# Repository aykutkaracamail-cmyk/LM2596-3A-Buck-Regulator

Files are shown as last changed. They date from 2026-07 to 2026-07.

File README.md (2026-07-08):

# KiCAD LM2596 Buck Regulator Project

Bu projede giriş gerilimini düşürerek çıkışa aktarmak amaçlanmıştır. Giriş gerilimini düşüren bu tip devrelere SMPS (Switched-Mode Power Supply) devreleri denilmiş olup, bu proje özelinde LM2596-ADJ entegresi kullanılmıştır. 

Çıkıştaki ani akım ihtiyacını karşılayabilmek ve voltaj çakılmasını engelleyebilmek için giriş kısmında 50V dayanımlı iki tane 470 uF'lık polarize kondansatör kullanılmıştır. Anahtarın açık olduğu esnada yük üzerindeki akımı kaybetmemek amacıyla endüktans 68 uH olarak seçilmiş olup, devreden geçecek olan maksimum akımın 3A düzeyinde olması planlandığından ters yön diyotu Schottky (5A) olarak seçilmiştir. Ayrıca yükün üstündeki gerilimin ripple (dalgalanma) katsayısının düşürülmesi amacıyla çıkışa paralel bağlı olan iki tane 220 uF'lık 35V dayanımlı polarize kondansatör kullanılmıştır. Versiyonlar arası komponentler değişiklik gösterebilir. Güncel stok durumları ve üretim maaliyetleri nedeniyle komponentler değiştirilmiştir.

📊 LTspice Simülasyon Sonucu



📊 PCB İlk Bakış



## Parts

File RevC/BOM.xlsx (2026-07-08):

Category | Quantity | References | Value | Package | Stock Code | Unit Cost | Tedarikçi Firma | Stok Adedi | Unit Cost (100 Adet) | Cost (100 adet kart) | Unit Cost (500 Adet) | Cost (500 adet kart) | Unit Cost (1000 Adet) | Cost (1000 adet kart) | Alternatif | Tedarikçi Firma
Capacitors | 2 | C1,C4 | 470 uF 50 V | Through Hole, D10mm×L20mm (P=5mm) | 01EC4236 (https://www.lcsc.com/product-detail/C2760863.html) | 0.10300 USD (en az 5 tane) | LCSC | 2720 | 0.08310 USD | 0.0831*200=16.62 USD (kondansatörlerden 200 tane alınmıştır) | 0.06050 USD | 0.0605*1000=60.50 USD (kondansatörlerden 1000 tane alınmıştır) | 0.06050 USD | 0.0605*2000=121.00 USD (kondansatörlerden 2000 tane alınmıştır) | RVT1H471M1213 (https://www.lcsc.com/product-detail/Aluminum-Electrolytic-Capacitors-SMD_470uF-50V-20_C90272.html) | LCSC
Capacitors | 2 | C2,C3 | 100 nF 50 V | 0402 | C0402B104K500NT (https://www.lcsc.com/product-detail/C17702730.html) | 0.00530 USD (en az 100 tane) | LCSC | 3100 | 0.00530 USD | 0.0053*200=1.06 USD (kondansatörlerden 200 tane alınmıştır) | 0.00420 USD | 0.0042*1000=4.20 USD (kondansatörlerden 1000 tane alınmıştır) | 0.00420 USD | 0.0042*2000=8.40 USD (kondansatörlerden 2000 tane alınmıştır) | CC0402KRX7R9BB104 (https://www.lcsc.com/product-detail/C131394.html) | LCSC
Inductor | 1 | L1 | 47 uH 3 A ISAT 4.5 A | SMD, 11.5×10.2×4.0mm | SMMS1040-470M (https://www.lcsc.com/product-detail/C149599.html) | 0.19380 USD (en az 5 tane) | LCSC | 64135 | 0.15080 USD | 0.1508*100=15.08 USD | 0.12980 USD | 0.1298*500=64.90 USD | 0.11110 USD | 0.1111*1000=111.10 USD | CYH127-47UH (https://www.lcsc.com/product-detail/Inductors-SMD_SHOU-HAN-CYH127-47UH_C2929503.html) | LCSC
Miscellaneous | 2 | J1,J2 | - | Through Hole, P=3.5mm (2 kutup) | DB301V-3.5-2P-GN-S (https://www.lcsc.com/product-detail/C695629.html) | 0.08420 USD (en az 5 tane) | LCSC | 97295 | 0.06170 USD | 0.0617*200=12.34 USD (konnektörlerden 200 tane alınmıştır) | 0.05010 USD | 0.0501*1000=50.10 USD (konnektörlerden 1000 tane alınmıştır) | 0.04790 USD | 0.0479*2000=95.80 USD (konnektörlerden 2000 tane alınmıştır) | KF350-3.5-2P (https://www.lcsc.com/product-detail/C474892.html) | LCSC
Resistor | 1 | R1 | 1K Ohm 150 V 125 mW | 0805 | FRC0805F1001TS (https://www.lcsc.com/product-detail/C2907232.html) | 0.00410 USD (en az 100 tane) | LCSC | 3593700 | 0.00410 USD | 0.0041*100=0.41 USD | 0.00410 USD | 0.0041*500=2.05 USD | 0.00350 USD | 0.0035*1000=3.50 USD | RC0805FR-071KL (https://www.lcsc.com/product-detail/Chip-Resistor-Surface-Mount_1KR-1000-1_C95781.html) | LCSC
Diode | 1 | D1 | 3 A 60 V | DO-214AC | SS36 (https://www.lcsc.com/product-detail/C727061.html) | 0.03390 USD (en az 20 tane) | LCSC | 151120 | 0.03390 USD | 0.0339*100=3.39 USD | 0.02780 USD | 0.0278*500=13.90 USD | 0.02450 USD | 0.0245*1000=24.50 USD | SS36 (https://www.lcsc.com/product-detail/Schottky-Barrier-Diodes-SBD_MDD-Microdiode-Electronics-SS36_C16015.html) | LCSC
Integrated Curcuit | 1 | U1 | LM2596S-ADJ | TO-263-5L | LM2596S-ADJ (https://www.lcsc.com/product-detail/C42421960.html) | 0.68710 USD | LCSC | 1617 | 0.41750 USD | 0.4175*100=41.75 USD | 0.37690 USD | 0.3769*500=188.45 USD | 0.35580 USD | 0.3558*1000=355.80 USD | LM2596S-ADJ (https://www.lcsc.com/product-detail/DC-DC-Converters_JSMSEMI-LM2596S-ADJ-P_C963385.html) | LCSC
Potentiometer | 1 | RV1 | 10K Multiturn | Through Hole, 9.5×4.8mm | 3296W-103-LF (https://www.lcsc.com/product-detail/C48641847.html) | 0.17810 USD (en az 5 tane) | LCSC | 1730 | 0.14230 USD | 0.1423*100=14.23 USD | 0.10780 USD | 0.1078*500=53.90 USD | 0.10780 USD | 0.1078*1000=107.80 USD | 3296W-1-103 (https://www.lcsc.com/product-detail/Precision-Potentiometer_10KR_C118954.html) | LCSC
TOPLAM |  |  |  |  |  |  |  |  |  | 104.88 USD (kart başına 1.0488 USD) |  | 438.00 USD (kart başına 0.8760 USD) |  | 827.90 USD (kart başına 0.8279 USD)
Klemenssiz toplam |  |  |  |  |  |  |  |  |  | 92.54 USD (kart başına 0.9254 USD) |  | 387.9 USD (Kart başına 0.7758 USD) |  | 732.1 USD (kart başına 0.7321 USD)
 |  |  |  |  |  |  |  |  |  |  | .

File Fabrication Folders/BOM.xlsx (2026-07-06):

Category | Quantity | References | Value | Package | Stock Code | Unit Cost | Tedarikçi Firma | Stok Adedi | 100 Tane İçin Fiyat(Özdisan) | 500 Tane İçin Fiyat(Özdisan) | 1000 Tane İçin Fiyat(Özdisan) | Alternatif | Tedarikçi Firma | 100 Adet En Ucuz Fiyat | 500 Adet En Ucuz Fiyat | 1000 Adet En Ucuz Fiyat
Capacitors | 2 | C1,C2 | 470 uF 50 V | Radial_D10.0mm_P5.00mm_L20.00mm | PKRM-050V471MG200-T/A5.0 (https://www.ozdisan.com/p/aluminyum-kapasitorler-180/koshin-pkrm-050v471mg200-t-a5-0-349988) | 0.10440 USD | Özdisan | 41255 | 0.10440*100=10.44 USD | 0.09000*500=45.00 USD | 0.0828*1000=82.80 USD | KM477M050G20RR0VH2FP0 (https://lcsc.com/product-detail/Aluminum-Electrolytic-Capacitors-Leaded_Dongguan-Chengxing-Elec-Dongguan-Chengxing-Elec-470uF-50V_C34642.html) | LCSC | 0.1035*100=10.35 USD | 0.0794*500=39.70 USD | 0.0794*1000=79.40 USD
Capacitors | 2 | C3,C4 | 220 uF 35 V | Radial_D8.0mm_P5.00mm_L11.50mm | PKRM-035V221MF115-T/A5.0 (https://www.ozdisan.com/p/aluminyum-kapasitorler-180/koshin-pkrm-035v221mf115-t-a5-0-342579) | 0.10440 USD | Özdisan | 101166 | 0.02840*100=2.84 USD | 0.02448*500=12.24 USD | 0.02448*1000=24.48 USD | KM227M035F12RR0VH2FP0 (https://lcsc.com/product-detail/Aluminum-Electrolytic-Capacitors-Leaded_LCSC-220uF-35V_C2063.html) | LCSC | 0.0372*100=3.72 USD | 0.0297*500=14.85 USD | 0.0266*1000=26.60 USD
Inductor | 1 | L1 | 68 uH 3.2 A | Inductor_SMD:L_12x12mm_H10mm | 7447709680 (https://www.ozdisan.com/p/sabit-induktorler-468/wurth-7447709680-514624) | 0.01518 USD | Özdisan | 815 | 1.69556*100=169.556 USD | 1.55991*500=779.955 USD | Yeterli Stok Yok | CYH125-68UH (https://www.lcsc.com/product-detail/C7431083.html) | LCSC | 0.2789*100=27.89 USD | 0.2065*500=103.25 USD | 0.2065*1000=206.50 USD
Miscellaneous | 2 | J1,J2 | - | TerminalBlock_Phoenix_PT-1,5-2-3.5-H_1x02_P3.50mm_Horizontal | DG381-3.5-02P-14-00AH (https://www.ozdisan.com/p/pcb-klemensler-410/degson-dg381-3-5-02p-14-00ah-599788) | 0.13392 USD | Özdisan | 8936 | 0.12528*100=12.528 USD | 0.11664*500=58.32 USD | 0.108*1000=108 USD | KF350-3.5-2P (https://lcsc.com/product-detail/Screw-terminal_Cixi-Kefa-Elec-KF350-3-5-2P_C474892.html) | LCSC | 0.0969*100=9.69 USD | 0.0781*500=39.05 USD | 0.0781*1000=78.10 USD
Resistor | 1 | R1 | 1K | 0805(2012) | CRT05F7E1001 (https://www.ozdisan.com/p/smt-smd-ve-cip-direncler-194/viking-crt05f7e1001-1054385) | 0.0000179 USD | Özdisan | 339229 | 0.00179*100=0.179 USD | 0.00168*500=0.84 USD | 0.00156*1000=1.56 USD | RMC08055.1K1%N (https://lcsc.com/product-detail/Chip-Resistor-Surface-Mount_Tyohm-RMC08055-1K1-N_C269748.html) | LCSC | 0.0062*100=0.62 USD | 0.0062*500=3.10 USD | 0.0049*1000=4.90 USD
Diode | 1 | D1 | 5A Schottky 40 V | DO214AB | SK54-HT (https://www.ozdisan.com/p/schottky-diyotlar-385/hottech-sk54-ht-475561) | 0.03248 USD | Özdisan | 5647 | 0.06048*100=6.048 USD | 0.05152*500=25.76 USD | 0.05152*1000=51.52 USD | SS54C (https://www.lcsc.com/product-detail/C16103.html) | LCSC | 0.0678*100=6.78 USD | 0.0542*500=27.10 USD | 0.0542*1000=54.20 USD
Integrated Curcuit | 1 | U1 | LM2596R-ADJ | TO263-5 (D2PAK) | LM2596R-ADJ-HTC (https://www.ozdisan.com/p/dc-dc-voltaj-regulatorleri-275/htc-lm2596r-adj-htc-587696) | 1.35720 USD | Özdisan | 2585 | 1.35720*100=135.72 USD | 1.17*500=585 USD | 1.07640*1000=1,076.4 USD | LM2596S-ADJ/TR (https://www.lcsc.com/product-detail/Others_HGSEMI-LM2596S-ADJ-TR_C194351.html) | LCSC | 0.3019*100=30.19 USD | 0.2483*500=124.15 USD | 0.2321*1000=232.10 USD
Potantiometer | 1 | RV1 | 10K Multiturn | Potentiometer_Bourns_3296W_Vertical(TUBE) | 3296W-1-103LF-BN (https://www.ozdisan.com/p/trimpot-potansiyometreler-396/bonens-3296w-1-103lf-bn-487776) | 0.13294 USD | Özdisan | 15125 | 0.10543*100=10.543 USD | 0.10121*500=50.605 USD | 0.10121*1000=101.21 USD | 3296W-1-103LF (https://lcsc.com/product-detail/Variable-Resistors-Potentiometers_BOURNS-3296W-1-103LF_C34846.html) | LCSC | 0.6465*100=64.65 USD | 0.6238*500=311.90 USD | 0.6091*1000=609.10 USD
TOPLAM |  |  |  |  |  |  |  |  | $347.85 | $1557.72 | $1445.97 |  |  | $153.89 | $663.10 | $1290.90

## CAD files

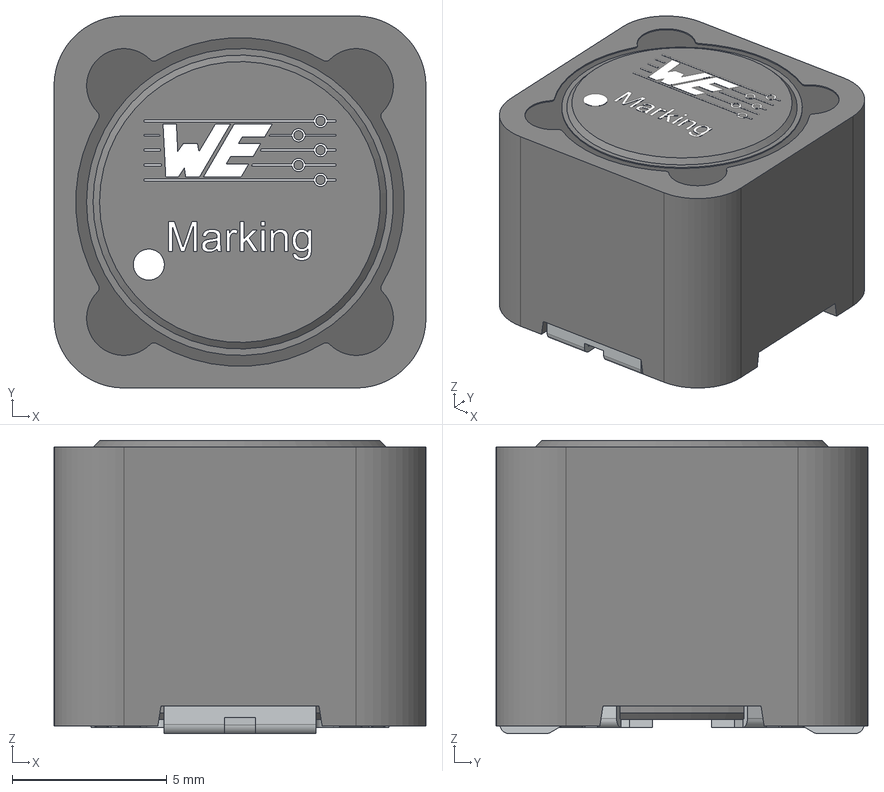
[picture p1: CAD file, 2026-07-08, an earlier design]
RevA/Download_WE-PD_1210_STP+%28rev1%29.stp
12.0 x 12.0 x 9.46 mm
Core
ShieldRing
Glue
Leadframe

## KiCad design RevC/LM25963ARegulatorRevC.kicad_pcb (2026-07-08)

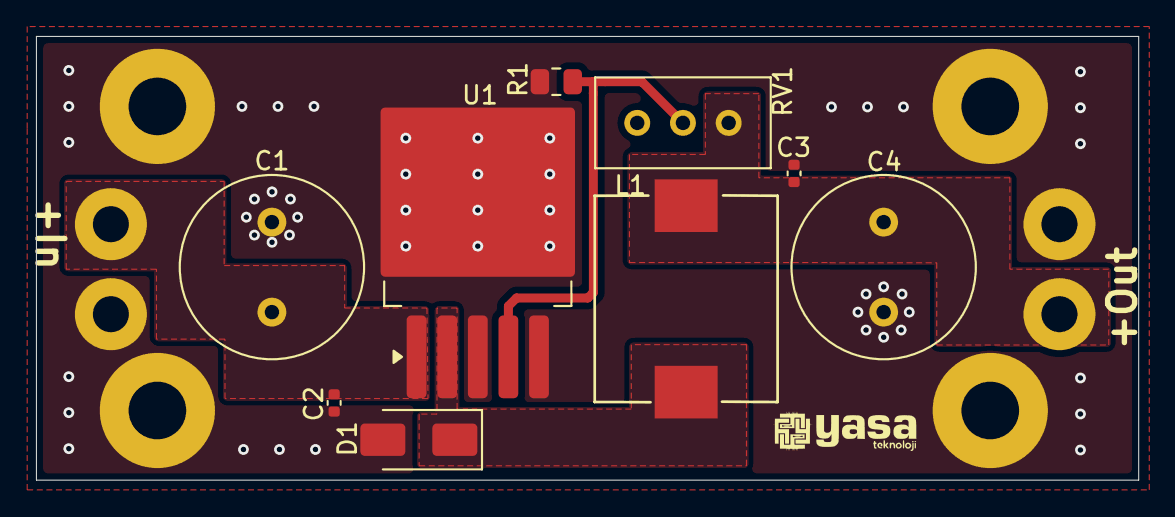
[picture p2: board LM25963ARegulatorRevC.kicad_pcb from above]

Board: 2 copper layers, 61.2 x 24.6 mm, 9 parts (0 on the bottom side), 5 nets.

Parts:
C1, C4: 470 uF 50 V; C_Radial_D10.0mm_H20.0mm_P5.00mm
C2, C3: 100 nF 50 V; C_0402_1005Metric
D1: 3A 60 V; D_SMA
L1: 47 uH 3A ISAT 4.5 A; IND-SMD_L11.5-W10.0_SMMS1040
R1: 1K Ohm 150 V 125 mW; R_0805_2012Metric
RV1: 10 K Ohm Multiturn; Potentiometer_Bourns_3296W_Vertical
U1: LM2596S-ADJ; TO-263-5_TabPin3

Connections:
GND: C1.2, C2.2, C3.2, C4.2, D1.2 (A), R1.1, U1.3 (GND), U1.5 (~ON/OFF)
unnamed: D1.1 (K), L1.1, U1.2 (OUT)
unnamed: C1.1, C2.1, U1.1 (VIN)
unnamed: C3.1, C4.1, L1.2, RV1.3
unnamed: R1.2, RV1.2, U1.4 (FB)

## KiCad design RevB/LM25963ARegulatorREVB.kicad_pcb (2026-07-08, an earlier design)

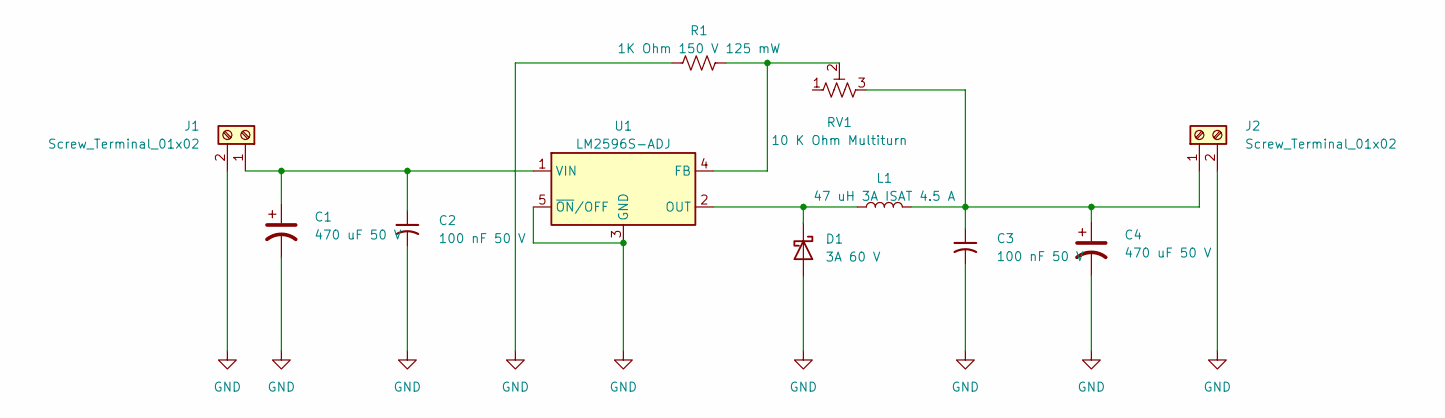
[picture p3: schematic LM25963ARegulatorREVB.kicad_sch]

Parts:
C1, C4: 470 uF 50 V; C_Radial_D10.0mm_H20.0mm_P5.00mm
C2, C3: 100 nF 50 V; C_0402_1005Metric
D1: 3A 60 V; D_SMA
J1, J2: Screw_Terminal_01x02; CONN-TH_DB301V-3.5-2P-GN
L1: 47 uH 3A ISAT 4.5 A; IND-SMD_L11.5-W10.0_SMMS1040
R1: 1K Ohm 150 V 125 mW; R_0805_2012Metric
RV1: 10 K Ohm Multiturn; Potentiometer_Bourns_3296W_Vertical
U1: LM2596S-ADJ; TO-263-5_TabPin3

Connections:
GND: C1.2, C2.2, C3.2, C4.2, D1.2 (A), J1.2, J2.2, R1.1, U1.3 (GND), U1.5 (~ON/OFF)
unnamed: D1.1 (K), L1.1, U1.2 (OUT)
unnamed: C1.1, C2.1, J1.1, U1.1 (VIN)
unnamed: C3.1, C4.1, J2.1, L1.2, RV1.3
unnamed: R1.2, RV1.2, U1.4 (FB)

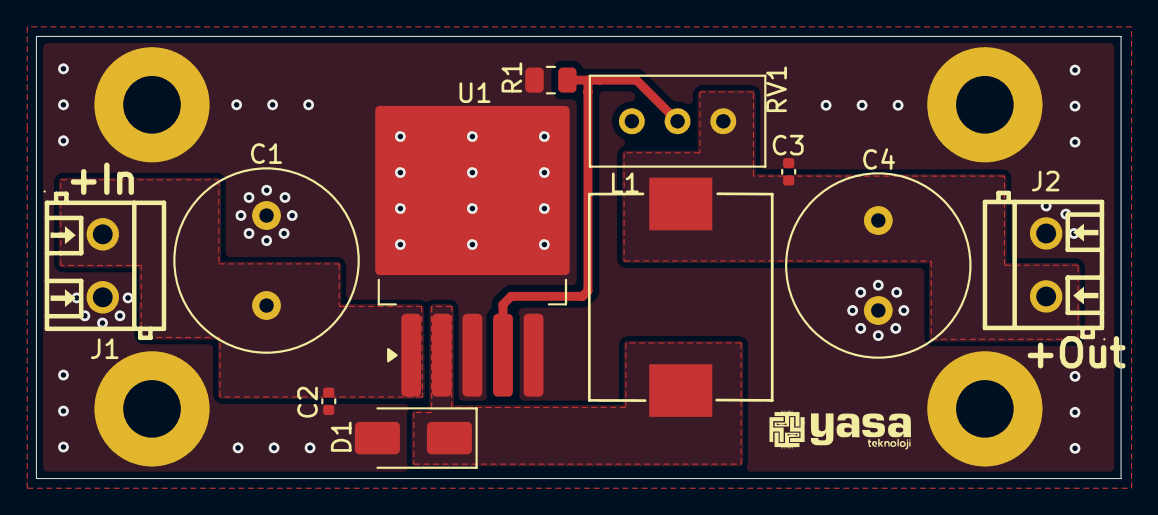
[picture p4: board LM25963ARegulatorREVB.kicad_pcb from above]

Board: 2 copper layers, 60.3 x 24.6 mm, 11 parts (0 on the bottom side), 5 nets.
